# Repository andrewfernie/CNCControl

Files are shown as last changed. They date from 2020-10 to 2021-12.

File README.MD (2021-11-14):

# GRBL Pendant

## Introduction
This project is a pendant for a GRBL CNC controller. It can act standalone, requiring connections only to the GRBL controller and to power, or can sit between a PC running a gcode sender application such as UGS and the GRBL controller. 

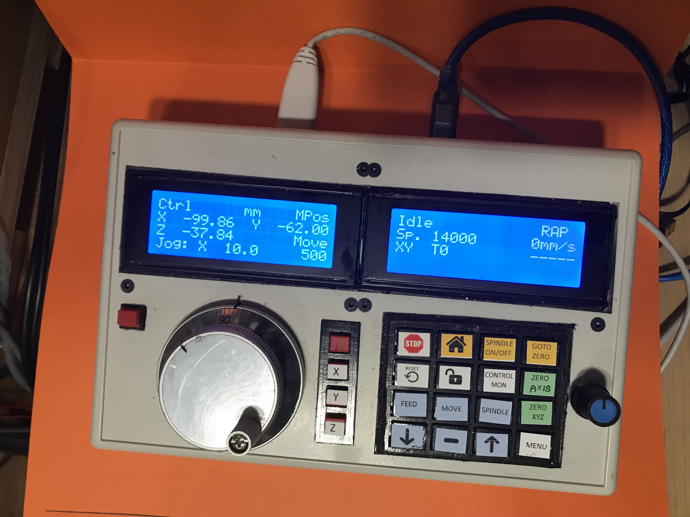
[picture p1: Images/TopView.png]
GRBLPendant


In the standalone configuration it can work in "control mode" to home the system, jog along a selected axis, and perform various reset, unlock, and zero axis operations.  

If running attached to a PC running a gcode sender, it can work in "monitor mode" where it listens to the traffic from the GRBL controller and displays X/Y/Z position, status, alarms, etc. This is the mode to use if the gcode sender is streaming commands. It can also be switched into control mode to send commands directly. All traffic from the  sender is intercepted and retransmitted to the controller so in principle it should be able to seamlessly inject commands into the stream from the sender but more work is required to ensure that the controller's communication buffer is handled properly.

Main control is via a "6 Terminal CNC Pulse Encoder" that can be switched to the X, Y, or Z axis. Distance for one revolution and feed rate can be modified by selecting the "move" or "feed" buttons then using the up and down arrows.

A second encoder with integral push button is provided for a menu system to configure the system, but this is not currently operational.

This version runs on a Teensy 4.1 which allows it to act as a USB host to drive the controller, in addition to acting as a USB device for the connection to a PC. An earlier version used a UART for communication to the controller and worked with a Teensy 3.2.

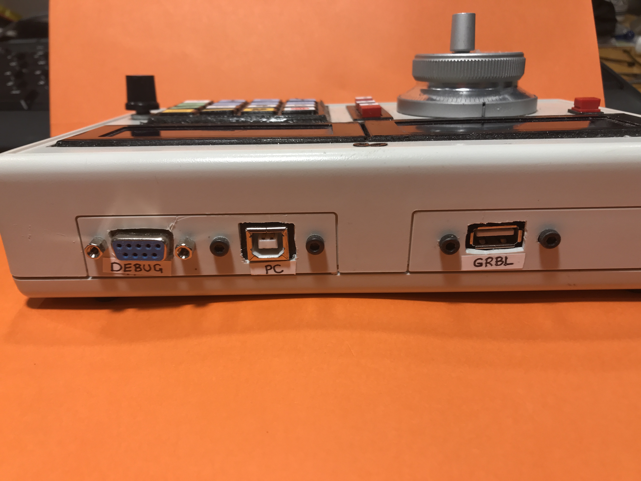
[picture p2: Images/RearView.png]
Rear Panel


## Components Used
It uses standard hardware available from all the usual sources. The main components are:
1. Teensy 4.1 https://www.pjrc.com/store/teensy41.html
2. Qty 2 20x4 LCD displays using I2C connections  (set to addressed 0x26 and 0x27) like this https://www.amazon.com/GeeekPi-Interface-Adapter-Backlight-Raspberry/dp/B086VVT4NH
3. One jog wheel encoder like this https://www.amazon.com/dp/B07G9G9VYC
4. Rotary encoder for menu system https://www.amazon.ca/Encoder-Development-Rotating-Potentiometer-Arduino/dp/B07H4L1N84
5. USB Type B panel mount to micro USB https://www.amazon.ca/Traovien-Printer-MacBook-Samsung-Printers/dp/B09FGPJNXN
6. USB Type A penel mount motherboard cable. Buy something like this and use only 1/2 of it. https://www.aliexpress.com/item/1005001419024926.html
7. 4x4 keypad https://www.amazon.ca/SunFounder-Matrix-Keypad-Arduino-Raspberry/dp/B015E32IXY

Twenty buttons in a 4x5 scanned matrix array are used for most control funtions. The 4x4 keypad to the right is a purchased array of microswitches to which I added 3D printed key caps and frame. The four in the left most row used for axis control and jog cancel were added later, and room was tight, so slightly smaller individual switches were used. The last four switches, as well as the one to the top left of the jog wheel, are 10mm x 10mm pushbuttons from my local electronics store. Starting over, a 4x5 array of identical switches would be nicer.  STL files for the key caps and frames are provided in the Hardware folder.

Stickers were printed on "printable vinyl" sheets https://www.aliexpress.com/item/1005003231276942.html. Images for the stickers are provided in the Hardware folder.

## Controls and Displays

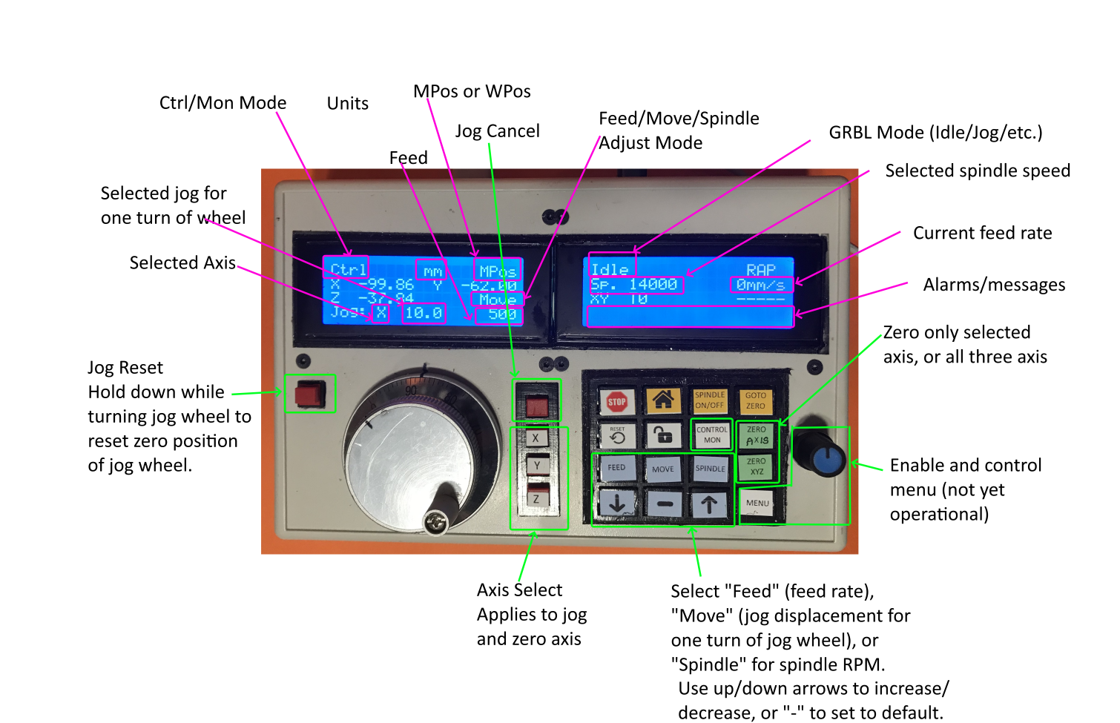
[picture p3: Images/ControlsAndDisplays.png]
Controls and Displays


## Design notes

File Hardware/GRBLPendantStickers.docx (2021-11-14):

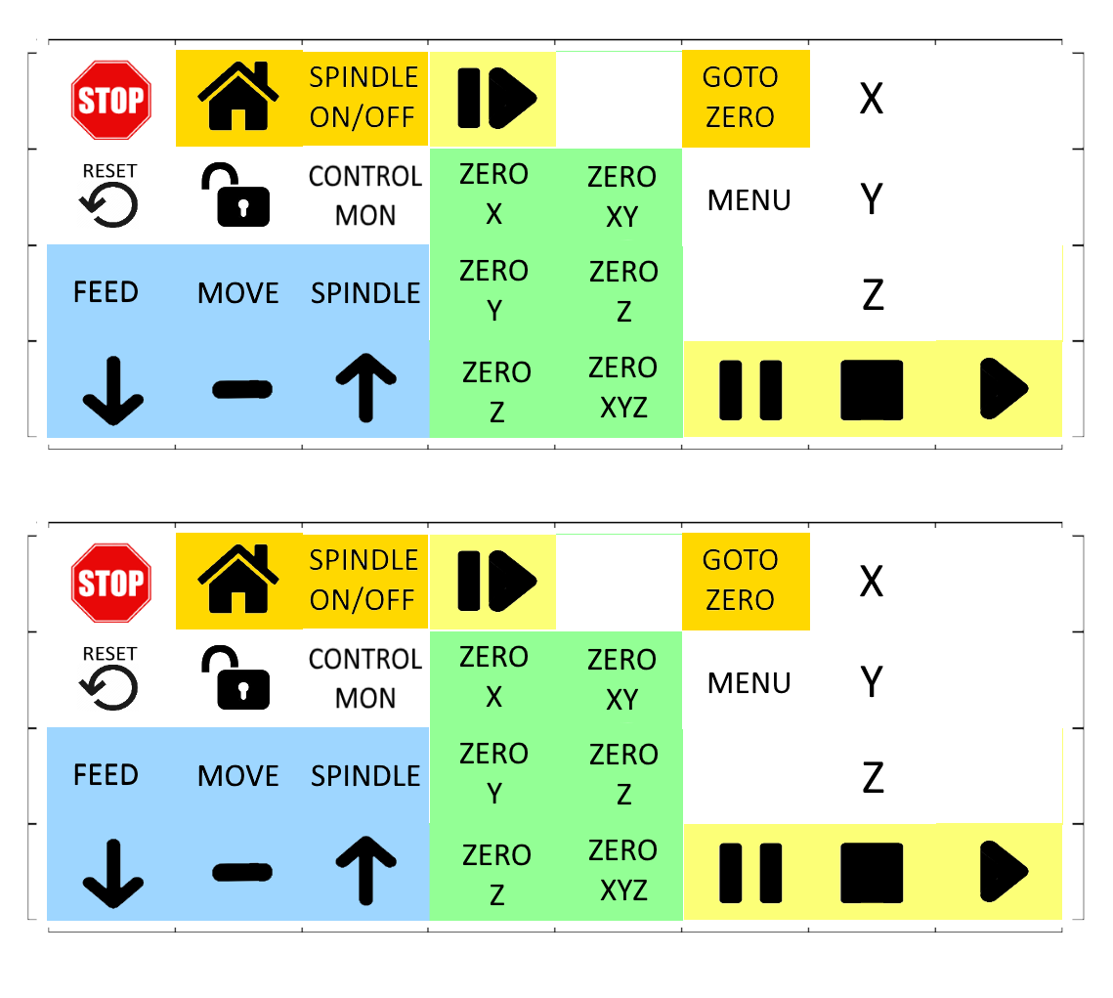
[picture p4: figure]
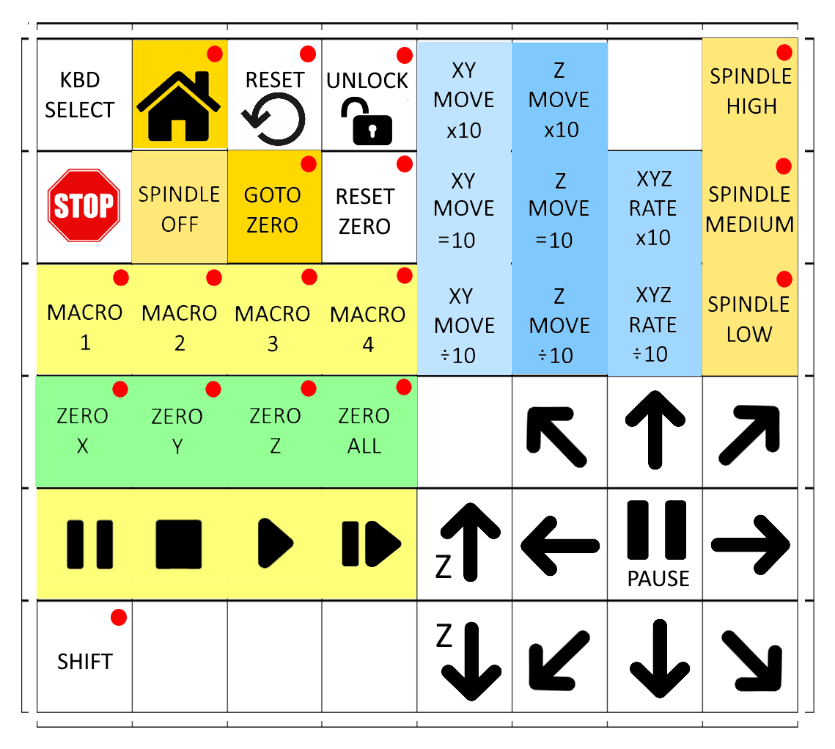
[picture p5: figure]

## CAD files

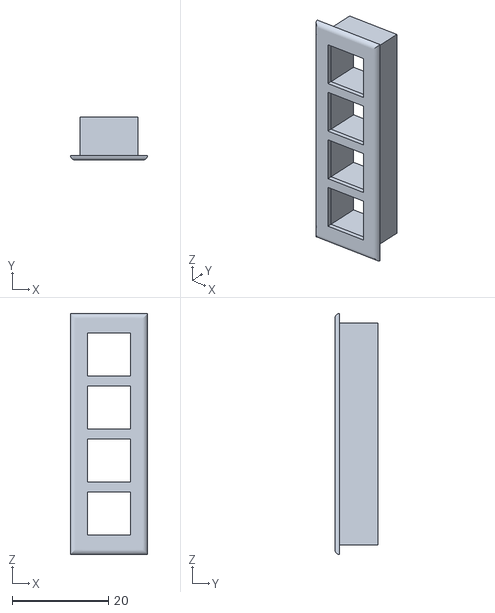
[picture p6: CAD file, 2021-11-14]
Hardware/Switch Bezel 4x1.stl
16.0 x 9.00 x 50.0

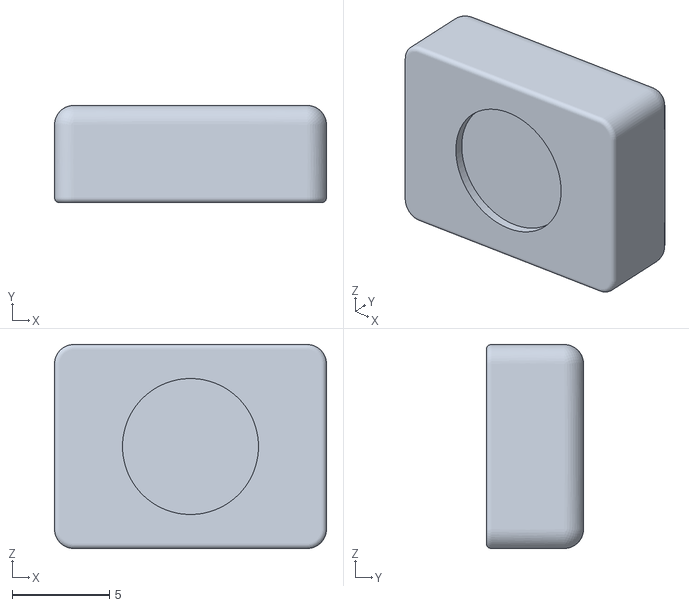
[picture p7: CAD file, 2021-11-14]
Hardware/ButtonCap.stl
14.0 x 5.00 x 10.5

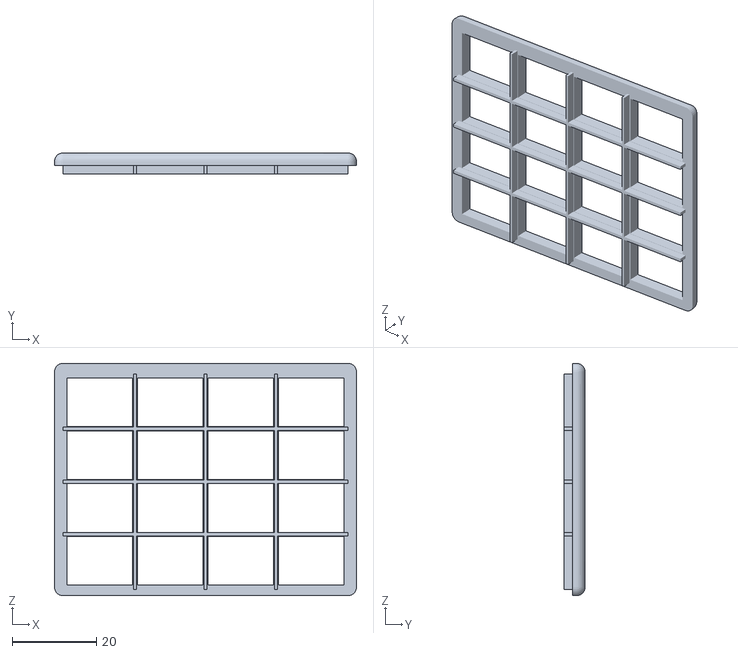
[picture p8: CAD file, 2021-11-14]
Hardware/Keypad Bezel 4x4 v7.stl
71.5 x 5.00 x 55.0

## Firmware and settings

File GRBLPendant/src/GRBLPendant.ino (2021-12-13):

//=========================================================
//Project: GRBL Pendant
//Module:  GRBLPendant.ino
//=========================================================
//
// GRBLPendant CNC control Copyright(C) 2021 Andrew Fernie
//
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
//=========================================================
//
// This project includes code from the  XLCD/SerialSpy
// project by Frank Herrmann.
// https://github.com/xpix/XLCD/tree/master/serialspy
//
//=========================================================
//
// ===============================================
// Includes
// ===============================================
//

#include <USBHost_t36.h>
#include <antplusdefs.h>
#include <Bounce2.h>
#include <Keypad.h>
#include <Key.h>
#include <EEPROM.h>
#include <Encoder.h>
#include <Wire.h>                // I2C Communication
#include <LiquidCrystal_I2C.h>   // LCD over I2C
#include "GRBLPendant.h"
#include "config.h"
#include "menu.h"
#include "lcd_screens.h"
#include "Encoder2.h"
#include "serial_io.h"
#include "key_commands.h"
#include "encoder_io.h"
#include "GRBL_io.h"

//
// ===============================================
// Defines
// ===============================================
//
constexpr auto ProgramVersion = "1.0.2";

//
// ===============================================
// Inits
// ===============================================
//
// -------------------------
// Inits for USB Host
// -------------------------

#ifdef GRBL_COMM_USB
USBHost grblUSB;
USBHub hub1(grblUSB);
USBHub hub2(grblUSB);
USBHIDParser hid1(grblUSB);
USBHIDParser hid2(grblUSB);
USBHIDParser hid3(grblUSB);
USBSerial grblUSBSerial(grblUSB);

USBDriver* drivers[] = { &hub1, &hub2, &hid1, &hid2, &hid3, &grblUSBSerial };
#define CNT_DEVICES (sizeof(drivers)/sizeof(drivers[0]))
const char* driver_names[CNT_DEVICES] = { "Hub1", "Hub2",  "HID1", "HID2", "HID3", "grblUSBSerial1" };
bool driver_active[CNT_DEVICES] = { false, false, false, false };
#endif

#ifdef GRBL_COMM_UART

#endif


// -------------------------
// Inits for LCD control
// -------------------------
// Set the pins on the I2C chip used for LCD connections:
//                         addr, en,rw,rs,d4,d5,d6,d7,bl,blpol
LiquidCrystal_I2C JogLCD(JogLCDAddress, LCD_EN, LCD_RW, LCD_RS, LCD_D4, LCD_D5, LCD_D6, LCD_D7, 3, POSITIVE);  // Set the LCD I2C address
LiquidCrystal_I2C StatusLCD(StatusLCDAddress, LCD_EN, LCD_RW, LCD_RS, LCD_D4, LCD_D5, LCD_D6, LCD_D7, 3, POSITIVE);  // Set the LCD I2C address

// -------------
// RotaryEncoder
// -------------

CEncoder2 uiEncoder(UI_ENC_A, UI_ENC_B, -4, UI_ENC_S);

long uiEncoderPosition = 0;
bool uiEncoderSwitch = false;


#ifdef JOG_ENC_A

CEncoder2 jogEncoder(JOG_ENC_A, JOG_ENC_B, 1);
Bounce jogResetButton = Bounce();
#endif

long lastStatusRXTime = 0;
long lastStateRXTime = 0;


// --------------
// System Timers
// --------------
uint32_t 		fast_loopTimer = 0;				// Time in miliseconds of main control loop
uint32_t 	    fast_loopTimeStamp = 0;			// Time Stamp when fast loop was complete
uint8_t 		delta_ms_fast_loop = 0; 		// Delta Time in miliseconds
int 			mainLoop_count = 0;

uint32_t 		medium_loopTimer = 0;			// Time in miliseconds of medium loop
byte 			medium_loopCounter = 0;			// Counters for branching from main control loop to slower loops
uint8_t			delta_ms_medium_loop = 0;

uint32_t 		slow_loopTimer = 0;				// Time in miliseconds of medium loop
byte 			slow_loopCounter = 0;
uint8_t 		delta_ms_slow_loop = 0; 		// Delta Time in miliseconds
byte 			superslow_loopCounter = 0;
byte			counter_one_herz = 0;

// ------------
// Keypad Setup
// ------------
const byte rows = 4; //four rows
const byte cols = 5; //four columns
char keys[rows][cols] = {
  {'1','2','3','4','5'},
  {'6','7','8','9','0'},
  {'A','B','C','D','E'},
  {'F','G','H','I','J'}
};
#ifdef TEENSY32
byte rowPins[rows] = {20, 21, 22, 23};  //connect to the row pinouts of the keypad
byte colPins[cols] = { 14, 15, 16, 17, 12 }; //connect to the column pinouts of the keypad
#else
byte rowPins[rows] = { 38, 39, 40, 41 }; //connect to the row pinouts of the keypad
byte colPins[cols] = {37, 36, 35, 34, 33};  //connect to the column pinouts of the keypad
#endif

Keypad keypad = Keypad(makeKeymap(keys), rowPins, colPins, rows, cols);

// ------------
// Pendant Mode
// ------------
PendantModes pendantMode = PendantModes::Monitor;

// ------------
// Set mode
// ------------
SetMode currentSetMode = SetMode::Move;

// ------------
// Menu Mode
// ------------
MenuModes menuMode = MenuModes::Status;

// --------------------------
// CNC Controller Status Data 
// --------------------------
unsigned long lastCall = 0;

// Motion Mode                 G0, G1, G2, G3, G38.2, G38.3, G38.4, G38.5, G80
MotionMode currentMotionMode = MotionMode::Undefined;

// Coordinate System Select    G54, G55, G56, G57, G58, G59
CoordinateSystemSelect currentCoordinateSystemSelect = CoordinateSystemSelect::Undefined;

// Plane Select                G17, G18, G19
PlaneSelect currentPlaneSelect = PlaneSelect::Undefined;

// Distance Mode               G90, G91
DistanceMode currentDistanceMode = DistanceMode::Undefined;

// Arc IJK Distance Mode       G91.1
ArcDistanceMode currentArcDistanceMode = ArcDistanceMode::On;

// Feed Rate Mode              G93, G94
FeedRateMode currentFeedRateMode = FeedRateMode::Undefined;

// Units Mode                  G20, G21
UnitsMode currentUnitsMode = UnitsMode::Undefined;

// Cutter Radius Compensation  G40
CutterRadiusCompensation currentCutterRadiusCompensation = CutterRadiusCompensation::Off;

// Tool Length Offset          G43.1, G49
ToolLengthOffsetMode currentToolLengthOffsetMode = ToolLengthOffsetMode::Undefined;

// Program Mode                M0, M1, M2, M30
ProgramMode currentProgramMode = ProgramMode::Undefined;

// Coolant State               M7, M8, M9
CoolantState currentCoolantState = CoolantState::Undefined;

// GRBL controller states
GRBLStates grblState = GRBLStates::Undefined;

// Co-ordinate system
GRBLCoord grblCoord = GRBLCoord::Undefined;

// Tool
char currentTool[] = "   ";

// Feed rate
float currentFeedRate = 0.0;

// Spindle speed
float spindleSpeed = 0.0;


float currentOvFeedRatePercent;  //Override Percent
float currentOvRapidRatePercent;  //Override Percent

char lastMessage[BufferSize];
unsigned long lastMessageTime = 0;
int  alarmNumber = 0;			// Alarm message number
unsigned long lastAlarmTime = 0;
int  errorNumber = 0;			// Error message number
unsigned long lastErrorTime = 0;

AxisData currentPosition;

AxisData currentWCO;

uint32_t  lastIdleTimeoutCheck = 0;

// --------------
// Jog parameters
// --------------
CNCAxis currentJogAxis = CNCAxis::X;

float   jogSize[] = { 1.0, 2.0, 5.0, 10.0, 20.0, 50.0, 100.0 }; // values are mm per encoder revolution. 
const uint8_t defaultJogSizeIndex = 3;
uint8_t maxJogSizeIndex = sizeof(jogSize) / sizeof(jogSize[0]) - 1;
uint8_t currentJogSizeIndex = defaultJogSizeIndex;
float   adjustableJogSize = 10.0;
uint8_t enableAdjustableJogSize = false;
bool stopJogCommand = false;



float   jogRate[] = { 50.0, 100.0, 200.0, 500.0, 1000.0, 2000.0 }; // values are "units" (mm or inches) per minute
const uint8_t defaultJogRateIndex = 3;
uint8_t maxJogRateIndex = sizeof(jogRate) / sizeof(jogRate[0]) - 1;
uint8_t currentJogRateIndex = defaultJogRateIndex;


// --------------
// Jog parameters
// --------------

// Spindle State               M3, M4, M5
SpindleState currentSpindleState = SpindleState::Off;
float currentSpindleSpeed = 0.0;

float   spindleRPM[] = { 8000.0, 10000.0, 12000.0, 14000.0, 16000.0, 18000.0, 20000.0, 22000.0, 24000.0 };
const uint8_t defaultSpindleRPMIndex = 3;
uint8_t maxSpindleRPMIndex = sizeof(spindleRPM) / sizeof(spindleRPM[0]) - 1;
uint8_t commandSpindleRPMIndex = defaultSpindleRPMIndex;
uint8_t actualSpindleRPMIndex = 0;

int grblCommandCount = 0;
int grbl_last_command_count = 0;
float lastJogCommandPosition = 0.0;

// --------------
// Menu 
// --------------

uint8_t menuVarUnits;
float   menuJogSpeedXY = 1.0;
float   menuJogSpeedZ = 1.0;

float menuVarDummy1;
int menuVarDummy2;
uint8_t menuVarDummy3;
uint8_t menuVarDummy4;

uint8_t menuEditMode;

struct MenuParameterItem menuParameters[] = {
    {ParamInMm,  "Units      ",  0,     0.,     0., (void*)&menuVarUnits},
    {ParamFloat, "Jog Spd. XY",  0,     0.,   100., (void*)&menuJogSpeedXY},
    {ParamFloat, "Jog Spd. Z ",  0,     0.,   100., (void*)&menuJogSpeedZ},
    {ParamFloat, "Dummy 1    ",  2,   -20.,   100., (void*)&menuVarDummy1},
    {ParamInt,   "Dummy 2    ",  0,  -999.,  1000., (void*)&menuVarDummy2},
    {ParamOnOff, "Dummy 3    ",  0,     0.,     0., (void*)&menuVarDummy3},
    {ParamYesNo, "Dummy 4    ",  0,     0.,     0., (void*)&menuVarDummy4}
};

Menu menuObject(menuParameters, sizeof(menuParameters) / sizeof(MenuParameterItem), &StatusLCD, &uiEncoderPosition);

// --------------
// IO buffers
// --------------
int pc = 0;
int gr = 0;
int pc_chars = 0;
int gr_chars = 0;
int loopCount = 0;
char pcserial[BufferSize];
char grserial[BufferSize];
char lcdRowString[LCDCols];
uint32_t lastLCDOut = 0;

// ===============================================
// Main
// ===============================================
 //

 //  ---------- Setup  ----------- //

void setup()
{
    debugSerial.begin(DebugSerialSpeed);   // open serial for debug/status messages

    pinMode(DEBUG_BROWN, OUTPUT);
    pinMode(DEBUG_RED, OUTPUT);
    pinMode(DEBUG_ORANGE, OUTPUT);
    pinMode(DEBUG_YELLOW, OUTPUT);

#ifdef UI_ENC_Sxxx
    // set Select pin from Rotary Encoder to input
    pinMode(UI_ENC_S, INPUT);      // sets the encoder select digital pin
#endif

    uiEncoder.SetMinMaxPosition(0, 7);

    // Setup the first button with an internal pull-up :
    pinMode(JogResetPin, INPUT_PULLUP);
    // After setting up the button, setup the Bounce instance :
    jogResetButton.attach(JogResetPin);
    jogResetButton.interval(5); // interval in ms

   // init LCD Displays //

    StatusLCD.begin(LCDCols, LCDRows);
    JogLCD.begin(LCDCols, LCDRows);

    // This is the serial connect to PC, we get some commands
    // but we can also print some additional information about this module
    // and the parser from Client program will ignore this
    debugSerial.print(F("<GRBLPendant "));
    debugSerial.print(ProgramVersion);
    debugSerial.println(F(">"));
    debugSerial.println(F("<All commands start with a colon ':'>"));
    debugSerial.println(F("<Call help with ':?'>"));


    StatusLCD.setCursor(0, 0); // letter, row
    StatusLCD.print(F("GRBL Pendant "));
    StatusLCD.print(ProgramVersion);
    StatusLCD.setCursor(0, 1); // letter, row
    StatusLCD.print(F("Connect ... "));
    StatusLCD.setCursor(0, 2); // letter, row
    StatusLCD.print(F("Status LCD "));

    JogLCD.setCursor(0, 0); // letter, row
    JogLCD.print(F("GRBL Pendant "));
    JogLCD.print(ProgramVersion);
    JogLCD.setCursor(0, 1); // letter, row
    JogLCD.print(F("Connect ... "));
    JogLCD.setCursor(0, 2); // letter, row
    JogLCD.print(F("Jog LCD "));

    uiEncoder.SetMinMaxPosition(0, menuObject.GetNumMenuItems() - 1);

    delay(2000);


#ifdef GRBL_COMM_USB
    // open USB host port to GRBL
    grblUSB.begin();
#endif

#ifdef GRBL_COMM_UART
    // open serial port to GRBL
    grblSerial.begin(GRBLSerialSpeed);
#endif

    // reset grbl device (ctrl-X) for Universal Gcode Sender
    GrblCommWriteChar(0x18);

    // open serial port to G Code senser 
    gsSerial.begin(GSSerialSpeed);

    StatusLCD.clear();
    JogLCD.clear();

}//SETUP



//  ---------- Loop ----------- //
void loop()
{
    // Jobs

    USBDeviceCheck(USBBAUD, USBFORMAT);

    DEBUG_DIGITALWRITE_HIGH(DEBUG_BROWN);
    SerialIOGRBL();
    DEBUG_DIGITALWRITE_LOW(DEBUG_BROWN);

    DEBUG_DIGITALWRITE_HIGH(DEBUG_RED);
    SerialIOGS();
    DEBUG_DIGITALWRITE_LOW(DEBUG_RED);


    if (grblCommandCount != grbl_last_command_count)
    {
        //DEBUG_PRINT("Command Count:");
        //DEBUG_PRINTLN(grblCommandCount);
        grbl_last_command_count = grblCommandCount;
    }

    // Update the Bounce instance
    jogResetButton.update();

    // We want this to execute at 50Hz if possible
    // -------------------------------------------
    if (millis() - fast_loopTimer > 19) {

        delta_ms_fast_loop = millis() - fast_loopTimer;

        fast_loopTimer = millis();

        mainLoop_count++;

        // Execute the fast (nominal 50Hz) loop
        // ------------------------------------
        fast_loop();

        // Execute the medium loop (internally sub-banded by 5 to a nominal 10Hz)
        // -----------------------------------------------------------------------
        medium_loop();

        // Execute the slow (nominal 1Hz) loop
        // ------------------------------------
        counter_one_herz++;
        if (counter_one_herz >= 50)
        {
            one_second_loop();
            counter_one_herz = 0;
        }

        fast_loopTimeStamp = millis();

    }

}//LOOP


// Main loop
void fast_loop()
{
    long jogPosition = 0;

    // This is the fast loop
    // ---------------------
    DEBUG_DIGITALWRITE_HIGH(DEBUG_ORANGE);

    uiEncoderPosition = uiEncoder.GetPosition();
    uiEncoderSwitch = uiEncoder.ReadSwitch();

    if (uiEncoderSwitch)
    {
        if (menuMode == MenuModes::Menu)
        {
            if (!menuEditMode)
            {
                menuObject.EditItem(uiEncoderPosition);
                menuEditMode = false;
            }
        }
        else
        {
            menuEditMode = false;
        }
    }

    long jogResetButton = ReadJogResetButton();

    if (!jogResetButton)
    {
        jogPosition = jogEncoder.GetPosition();
    }
    else
    {
        jogPosition = 0;
        lastJogCommandPosition = 0.0;
        jogEncoder.Reset();
    }


#ifdef JOG_ENC_S
    jogEncoderSwitch = ReadJogEncoderSwitch();

    if (jogEncoderSwitch)
    {
        ResetJogEncoderCount();
    }
#endif

    if (pendantMode == PendantModes::Control)
    {
        float jog_move;

        if (!jogResetButton)
            jog_move = float(jogPosition) / JogEncCount * getJogSize();
        else
            jog_move = 0.0;

        if (stopJogCommand)
        {
            lastJogCommandPosition = jog_move;
        }
        else {
            if (fabs(jog_move - lastJogCommandPosition) >= 0.001)
            {
                if (grblCommandCount < 3)
                {
                    float jogDelta = jog_move - lastJogCommandPosition;
                    SendJogCommand(jogDelta);
                    lastJogCommandPosition = lastJogCommandPosition + jogDelta;
                }
            }
        }
    }
    stopJogCommand = false;
    DEBUG_DIGITALWRITE_LOW(DEBUG_ORANGE);

}

void medium_loop()
{
    // This is the start of the medium loop 
    // -----------------------------------------
    // The routine is called at 50Hz, so each of the five subbanded 
    // blocks is called at 10Hz

    char key;
    DEBUG_DIGITALWRITE_HIGH(DEBUG_YELLOW);

    switch (medium_loopCounter)
    {
    case 0:
        medium_loopCounter++;

        delta_ms_medium_loop = millis() - medium_loopTimer;
        medium_loopTimer = millis();

        break;

        //---------------------------------------------
    case 1:
        medium_loopCounter++;

        key = keypad.getKey();

        if (key != NO_KEY)
        {
            ProcessKey(key);
        }
        break;

        //------------------------------
    case 2:
        medium_loopCounter++;

        break;

        //--------------------------------------------
    case 3:
        medium_loopCounter++;

        break;

        // This case controls the slow loop
        //---------------------------------
    case 4:
        medium_loopCounter = 0;

        slow_loop();

        break;
    }
    DEBUG_DIGITALWRITE_LOW(DEBUG_YELLOW);

}

void slow_loop()
{
    // This is the slow (2Hz) loop pieces
    //----------------------------------------
    // The routine is called at 10Hz, so each of the five subbanded 
    // blocks is called at 2Hz


    switch (slow_loopCounter) {
    case 0:
        slow_loopCounter++;

        delta_ms_slow_loop = millis() - slow_loopTimer;
        slow_loopTimer = millis();

        if (menuMode == MenuModes::Status)
            DisplayState();
        else
            menuObject.Draw();

        break;

    case 1:
        slow_loopCounter++;

        DisplayJogScreen();

        break;

    case 2:
        slow_loopCounter++;

        if ((pendantMode == PendantModes::Control) && (millis() - lastStatusRXTime > 1000))
        {
            SendGRBLCommand_NoCount("?");
        }
        break;

    case 3:
        slow_loopCounter++;

        if ((pendantMode == PendantModes::Control) && (millis() - lastStateRXTime > 1000))
        {
            SendGRBLCommand("$G\n");
        }

        break;

    case 4:
        slow_loopCounter = 0;

        break;
    }

}

void one_second_loop()
{
    if (pendantMode == PendantModes::Control)
    {
        if (grblState == GRBLStates::Idle)
        {
            if (millis() - lastIdleTimeoutCheck > 5000)
            {
                ResetGRBLCommandCount();
            }
        }
        else
        {
            lastIdleTimeoutCheck = millis();
        }
    }
    else
    {
        grblCommandCount = 0;
    }
}

// ---------- Subroutines -----------

//
// split a string on one or more delimiter
// and return split at index
// split(char* string[] = "1,2;3")
//
char* split(char* string, char* delimiter, int index)
{
    char* ptr;

    char buffer[BufferSize];
    strcpy(buffer, string);

    // init and create first cut
    ptr = strtok(buffer, delimiter);
    int x = 0;
    while (ptr != NULL) {
        if (x++ >= index)
            break;
        // next one
        ptr = strtok(NULL, delimiter);
    }

    return ptr;
}


void set_grblState_from_chars(char* tmp)
{
    if (strcmp(tmp, "Idle") == 0)    grblState = GRBLStates::Idle;
    if (strcmp(tmp, "Run") == 0)     grblState = GRBLStates::Run;
    if (strcmp(tmp, "Hold") == 0)    grblState = GRBLStates::Hold;
    if (strcmp(tmp, "Jog") == 0)     grblState = GRBLStates::Jog;
    if (strcmp(tmp, "Alarm") == 0)   grblState = GRBLStates::Alarm;
    if (strcmp(tmp, "Door") == 0)    grblState = GRBLStates::Door;
    if (strcmp(tmp, "Check") == 0)   grblState = GRBLStates::Check;
    if (strcmp(tmp, "Home") == 0)    grblState = GRBLStates::Home;
    if (strcmp(tmp, "Sleep") == 0)   grblState = GRBLStates::Sleep;
}

float getJogRate()
{
    return jogRate[currentJogRateIndex];
}

uint8_t setJogRateIndex(uint8_t index)
{
    currentJogRateIndex = max(0, min(index, maxJogRateIndex));
    return currentJogRateIndex;
}

uint8_t setJogRateDefault()
{
    currentJogRateIndex = defaultJogRateIndex;
    return currentJogRateIndex;
}

uint8_t incrementJogRateIndex()
{
    if (currentJogRateIndex < maxJogRateIndex)
    {
        currentJogRateIndex++;
    }
    return currentJogRateIndex;
}

uint8_t decrementJogRateIndex()
{
    if (currentJogRateIndex > 0)
    {
        currentJogRateIndex--;
    }
    return currentJogRateIndex;
}


float getJogSize()
{
    return jogSize[currentJogSizeIndex];
}

uint8_t setJogSizeIndex(uint8_t index)
{
    currentJogSizeIndex = max(0, min(index, maxJogSizeIndex));
    enableAdjustableJogSize = false;
    return currentJogSizeIndex;
}

uint8_t setJogSizeDefault()
{
    currentJogSizeIndex = defaultJogSizeIndex;
    enableAdjustableJogSize = false;
    return currentJogSizeIndex;
}

uint8_t incrementJogSizeIndex()
{
    if (currentJogSizeIndex < maxJogSizeIndex)
    {
        currentJogSizeIndex++;
    }
    enableAdjustableJogSize = false;
    return currentJogSizeIndex;
}

uint8_t decrementJogSizeIndex()
{
    if (currentJogSizeIndex > 0)
    {
        currentJogSizeIndex--;
    }
    enableAdjustableJogSize = false;
    return currentJogSizeIndex;
}



float getSpindleRPM()
{
    return spindleRPM[commandSpindleRPMIndex];
}

uint8_t setSpindleRPMIndex(uint8_t index)
{
    commandSpindleRPMIndex = max(0, min(index, maxSpindleRPMIndex));
    return commandSpindleRPMIndex;
}

uint8_t setSpindleRPMDefault()
{
    commandSpindleRPMIndex = defaultSpindleRPMIndex;
    return commandSpindleRPMIndex;
}

uint8_t incrementSpindleRPMIndex()
{
    if (commandSpindleRPMIndex < maxSpindleRPMIndex)
    {
        commandSpindleRPMIndex++;
    }
    return commandSpindleRPMIndex;
}

uint8_t decrementSpindleRPMIndex()
{
    if (commandSpindleRPMIndex > 0)
    {
        commandSpindleRPMIndex--;
    }
    return commandSpindleRPMIndex;
}

uint8_t findClosestSpindleRPMIndex(float rpm)
{
    float lowest_delta = 9999999.;
    float delta;
    uint8_t closestIndex = 0;

    for (int i = 0; i <= maxSpindleRPMIndex; i++)
    {
        delta = fabs(rpm - spindleRPM[i]);
        if (delta < lowest_delta)
        {
            closestIndex = i;
            lowest_delta = delta;
        }
    }
    closestIndex = max(0, min(closestIndex, maxSpindleRPMIndex));

    return closestIndex;
}


uint32_t freeMem()
{
    // for Teensy 3.2
    uint32_t stackTop;
    uint32_t heapTop;

    // current position of the stack.
    stackTop = (uint32_t)&stackTop;

    // current position of heap.
    void* hTop = malloc(1);
    heapTop = (uint32_t)hTop;
    free(hTop);

    // The difference is (approximately) the free, available ram.
    return stackTop - heapTop;
}

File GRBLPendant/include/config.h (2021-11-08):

// config.h

#ifndef _CONFIG_h
#define _CONFIG_h

#if defined(ARDUINO) && ARDUINO >= 100
	#include "arduino.h"
#else
	#include "WProgram.h"
#endif

#include <USBHost_t36.h>

// Define one of the following depending on which model of Teensy is being used
// Changes pin defines and availability of USB Host mode (not supported by Teensy 3.2)
//#define TEENSY32
#define TEENSY41

// Normal serial for debug ----------------------------------
#define debugSerial     Serial3
constexpr auto DebugSerialSpeed = 115200  ;

// G-Code sender. Must be as fast as grbl!
#define gsSerial        Serial
constexpr auto GSSerialSpeed = 115200 ;

const int BufferSize = 100;

#ifdef TEENSY41
#define  GRBL_COMM_USB
const uint32_t USBBAUD = 115200;
const uint32_t USBFORMAT = USBHOST_SERIAL_8N1;
//#define USB_COMM_DEBUG
#else
#define  GRBL_COMM_UART
// Serial to GRBL
#define grblSerial      Serial2
constexpr auto GRBLSerialSpeed = 115200; 
#endif

// Command parameters

constexpr auto SpindleMaxSpeed = 24000;				// Max speed for spindle when turned on to 100%

constexpr auto SpindleDefaultSpeedPercent = 50	;		// Default spindle speed as percentage of SpindleMaxSpeed

// LCD -------------------------------------------
constexpr auto StatusLCDAddress = 0x26;  // I2C LCD Address
constexpr auto JogLCDAddress = 0x27;  // I2C LCD Address

constexpr auto LCDCols = 20;
constexpr auto LCDRows = 4;

#if(LCDCols==16)
constexpr auto LCDEmpty("                ");
#else
constexpr auto LCDEmpty = ("                    ");
#endif

// LCD controller pins
// Note that as we are using an I2C controller these are the pins
// on the controller, not the pins on the Teensy that is running this
// code.
constexpr auto LCD_EN = 2;
constexpr auto LCD_RW = 1;
constexpr auto LCD_RS = 0;
constexpr auto LCD_D4 = 4;
constexpr auto LCD_D5 = 5;
constexpr auto LCD_D6 = 6;
constexpr auto LCD_D7 = 7;


// UI Rotary Encoder --------------------------------
#define UI_ENC_A				4     // Encoder interrupt pin
#define UI_ENC_B				5     // Encoder second pin
#define UI_ENC_S				6     // Encoder select pin
const int UI_ENC_COUNT = 80;  // encoder count per rotation

// Rotary Encoder --------------------------------
#define JOG_ENC_A				2     // Encoder interrupt pin
#define JOG_ENC_B				3     // Encoder second pin
//#define JOG_ENC_S				4     // Encoder select pin
constexpr auto JogEncCount = 400;  // encoder count per rotation

constexpr auto JogResetPin = 11;


// Debug Pins --------------------------------
#ifdef TEENSY32
constexpr auto DEBUG_BROWN  = 24;
constexpr auto DEBUG_RED    = 25;
constexpr auto DEBUG_ORANGE = 26;
constexpr auto DEBUG_YELLOW = 27;
#else
constexpr auto DEBUG_BROWN = 29;
constexpr auto DEBUG_RED = 30;
constexpr auto DEBUG_ORANGE = 31;
constexpr auto DEBUG_YELLOW = 32; 
#endif

// EEPROM addresses
constexpr auto EEPROMButtons = 100;
constexpr auto EEPROMInterval = 150;

// only for debugging
#define DEBUG

#define DEBUG_IO

#ifdef DEBUG_IO
#define DEBUG_PRINT(str) debugSerial.print(str)
#define DEBUG_PRINTLN(str) debugSerial.println(str)
#define DEBUG_DIGITALWRITE(pin,value) digitalWrite(pin,value);
#define DEBUG_DIGITALWRITE_HIGH(pin) digitalWrite(pin,HIGH);
#define DEBUG_DIGITALWRITE_LOW(pin) digitalWrite(pin,LOW);
#else
#define DEBUG_PRINT(str)
#define DEBUG_PRINTLN(str)
#define DEBUG_DIGITALWRITE(pin,value)
#define DEBUG_DIGITALWRITE_HIGH(pin)
#define DEBUG_DIGITALWRITE_LOW(pin)
#endif

// Macros
#define COUNT_OF(x) ((sizeof(x)/sizeof(0[x])) / ((size_t)(!(sizeof(x) % sizeof(0[x])))))
#define min(a,b) ((a)<(b)?(a):(b))
#define max(a,b) ((a)>(b)?(a):(b))

#endif

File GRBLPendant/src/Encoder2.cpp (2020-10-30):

// 
// 
// 
#include "Encoder2.h"

CEncoder2::CEncoder2(uint8_t pin1, uint8_t pin2, int8_t divider) :Encoder{ pin1, pin2 }
{
	m_pinSwitch = 0;
	m_enableSwitch = false;
	m_divider = divider;
	Init();
}

CEncoder2::CEncoder2(uint8_t pin1, uint8_t pin2, int8_t divider, uint8_t pin_sw) : Encoder{ pin1, pin2 }
{
	m_pinSwitch = pin_sw;
	m_enableSwitch = true;
	m_divider = divider;
	pinMode(pin_sw, INPUT);      // sets the encoder select digital pin
	Init();
}

void CEncoder2::Init()
{
	SetScaleOffset(1.0, 0.0);
	SetMinMaxPosition(-999999, 999999);
	Reset();
}

//--------------------------------------------------------------------------------------
// GetPosition()
//--------------------------------------------------------------------------------------
long CEncoder2::GetPosition()
{
	m_lastCount = m_count;

	m_count = read() / m_divider;

	if (m_count > m_maximumPosition)
	{
		m_count = m_maximumPosition;
		write(m_count * m_divider);
	}
	else if (m_count < m_minimumPosition)
	{
		m_count = m_minimumPosition;
		write(m_count * m_divider);
	}

	if ((m_count - m_lastCount) > m_directionThreshold)
		m_direction = 1;
	else if ((m_count - m_lastCount) < -m_directionThreshold)
		m_direction = -1;
	else
		m_direction = 0;

	return m_count;
}

//--------------------------------------------------------------------------------------
// GetLastPosition()
//--------------------------------------------------------------------------------------
long CEncoder2::GetLastPosition()
{
	return m_lastCount;
}

//--------------------------------------------------------------------------------------
// GetLastScaledPosition()
//--------------------------------------------------------------------------------------
float CEncoder2::GetLastScaledPosition()
{
	return ((float)m_lastCount * m_scale) + m_offset;
}

//--------------------------------------------------------------------------------------
// GetScaledPosition()
//--------------------------------------------------------------------------------------
float CEncoder2::GetScaledPosition()
{
	return ((float)m_count * m_scale) + m_offset;
}

//--------------------------------------------------------------------------------------
// ReadJogEncoderSwitch(()
//--------------------------------------------------------------------------------------
bool CEncoder2::ReadSwitch()
{
	bool sw = false;

	if (m_enableSwitch)
	{
		sw = !digitalRead(m_pinSwitch);
	}
	return sw;
}

void CEncoder2::Reset()
{
	write(0);
	m_count = 0;
	m_lastCount = 0;
	m_direction = 0;
	m_scaledPosition = m_offset;
	m_lastScaledPosition = m_offset;
}

int8_t CEncoder2::GetDirection()
{
	return m_direction;
}

void CEncoder2::SetMinMaxPosition(long minPos, long maxPos)
{
	m_minimumPosition = minPos;
	m_maximumPosition = maxPos;
}

void CEncoder2::SetScaleOffset(float scale, float offset)
{
	m_scale = scale;
	m_offset = offset;
}

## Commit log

2020-01-02 Implement encoder based jog. Fix comm issues that upset UGS Fix state names
    [GRBLPendant.ino, encoder_io.ino, key_commands.ino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]
2020-01-06 Add second LCD Rework button assignments after assembling system.
    [GRBLPendant.ino, encoder_io.ino, key_commands.ino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]
2020-01-06 Create debug program to scan I2C address for LCD
2020-01-12 Added second encoder to be used for UI (not yet used for anything).
    Switched to Serial for comms to the g code sender. This is the Serial port from the micro-USB connector on the Teensy.
2020-01-19 Add menu key (no menu items defined yet). Allow display of MPos and WPos. Fix variable names for JogLCD and StatusLCD (they were inverted).
    [GRBLPendant.ino, key_commands.ino, lcd_screens.ino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]
2020-01-27 Started menu definitions
    [config.h]
2020-02-20 Added error and alarm message strings Reworked logic for display of alarms, messages, and errors Separate unlock and reset buttons. Required combining spindle on and off buttons into one on/off butto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
    [GRBLPendant.ino, key_commands.ino, lcd_screens.ino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]
2020-02-24 Added jog encoder reset button. Converted most numeric #define statements to "constexpr auto" and used camelcase for those parameters.
    [config.h]
2020-03-01 Added four more buttons. Currently for W/M, X, Y, and Z, but will eventually rework button assignments
    [GRBLPendant.ino, key_commands.ino]
2020-03-14 Create dedicated functions for common GRBL commands Try resetting serial IO each switching to control and monitor modes, and cut command buffer to 3 rather than 5 to try and resolve comm problem.
    [GRBLPendant.ino, key_commands.ino, serial_io.ino]
2020-03-18 Check for valid tokens from strtok calls and make sure grbl_command_count doesn't go below zero.
    [GRBLPendant.ino, serial_io.ino]
2020-03-21 Debug outputs
    [config.h]
2020-08-01 Convert more #define to constexpr Don't count both the command and the newline when sending string - only increement count by one.
    [config.h]
2020-08-01 Change I2C address of monitoring LCD Change button layout - XYZ go to left, new buttons for increasing/decreasing jog rate. New routines to support increment/decrement of jog rates
    [config.h]
2020-08-02 Jog size now uses increment/decrement approach like the jog rate approach.
    Converted some variable and function names to camel case
2020-08-10 Add FeedHold method and call it with button 'G' No CRLF with 0x18 and !(feed hold) More camel case
2020-08-12 New Encoder2 library. Only used for jog encoder for now.
2020-08-13 Improvements to CEncoder2 class and convert UI encoder to use CEncoder2
2020-10-30 Add USB host mode for communication with GRBL controller. Requires Teensy 4.1
2020-10-31 Update pins for Teensy 4.1 version Use #define/#ifdef to select between Teensy 3.2 and 4.1 Teensy 3.2 comm to GRBL always via UART, Teensy 4.1 always via USB host
    [config.h]
2020-11-09 Add USBDeviceCheck function to detect device on USB host and reconnect as needed.
    [config.h]
2020-11-19 Set default spindle speed. Default set by constexpr, but results in a foat variable so that it can be modified during at run-time after more coding.
    [config.h]
2021-10-24 Check on jog encoder reset button before using jog encoder data
2021-11-08 Mainly updates to keyboard layout and commands executed from the keyboard. Also, move to new spindle, with spindle speed changes possbile from the keys.
    Working well, mainly just the menu system that needs to be completed.
    [config.h]
2021-11-14 Move to PlatformIO Reassignment of keys Generally working other than remaining work items below. Remaining work - menu system - support UGS communication from PC simultaneously with comms from the pe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
    [ButtonCap.stl, Keypad Bezel 4x4 v7.stl, Switch Bezel 4x1.stl]
2021-11-19 Changed pin definitions and setup for keypad. No change in functionality, but prior to the change the rows and columns were swapped, and the columns were backwards. This chamnge just makes it easier 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
    [GRBLPendant.ino, key_commands.ino]
2021-12-13 V1.0.2 - Disabled all but STOP command while in monitor mode - Fix bugs with spindle speed control. Command was being overwritten by the value received from the controller.
    [GRBLPendant.ino, GRBL_io.ino, key_commands.ino]

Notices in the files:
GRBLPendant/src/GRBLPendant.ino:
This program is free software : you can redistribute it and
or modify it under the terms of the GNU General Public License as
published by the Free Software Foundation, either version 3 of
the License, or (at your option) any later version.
